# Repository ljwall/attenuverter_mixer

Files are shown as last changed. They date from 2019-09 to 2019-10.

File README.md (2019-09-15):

# Eurorack attenuverter and mixer module

Four channels, each with input -> attenuverter control -> output. Each input is
normaled to +5v if there is no jack in the input. Each output channel (after the
attenuverting stage) is also sent to a summing mixer, and to an analogue logic
or, a.k.a. the peaks part from [peaks and troughs](https://www.elby-designs.com/webtek/cgs/cgs26/cgs26_analogic.html).

If an individual output chnanel is patched, it's removed from the summing mixer
and the peaks output.

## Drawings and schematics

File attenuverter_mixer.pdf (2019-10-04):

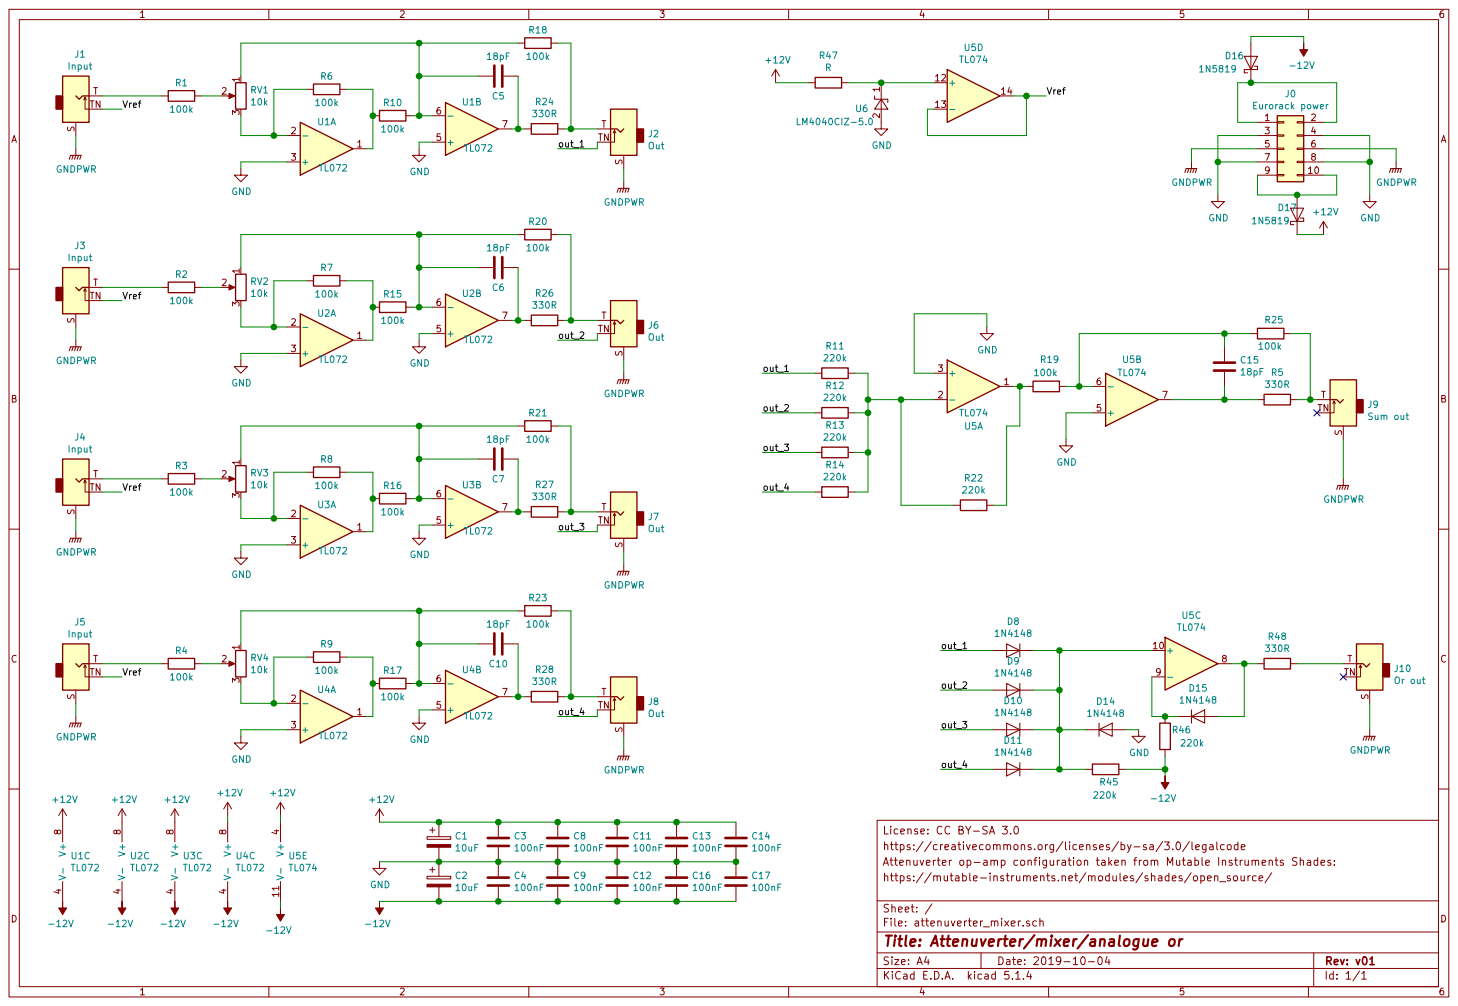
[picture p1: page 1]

9 | | 10

https://creativecommons.org/licenses/by-sa/3.0/legalcode
Attenuverter op-amp configuration taken from Mutable Instruments Shades:
File: attenuverter_mixer.sch Sheet: / https://mutable-instruments.net/modules/shades/open_source/

Id: 1/1 Title: Attenuverter/mixer/analogue or

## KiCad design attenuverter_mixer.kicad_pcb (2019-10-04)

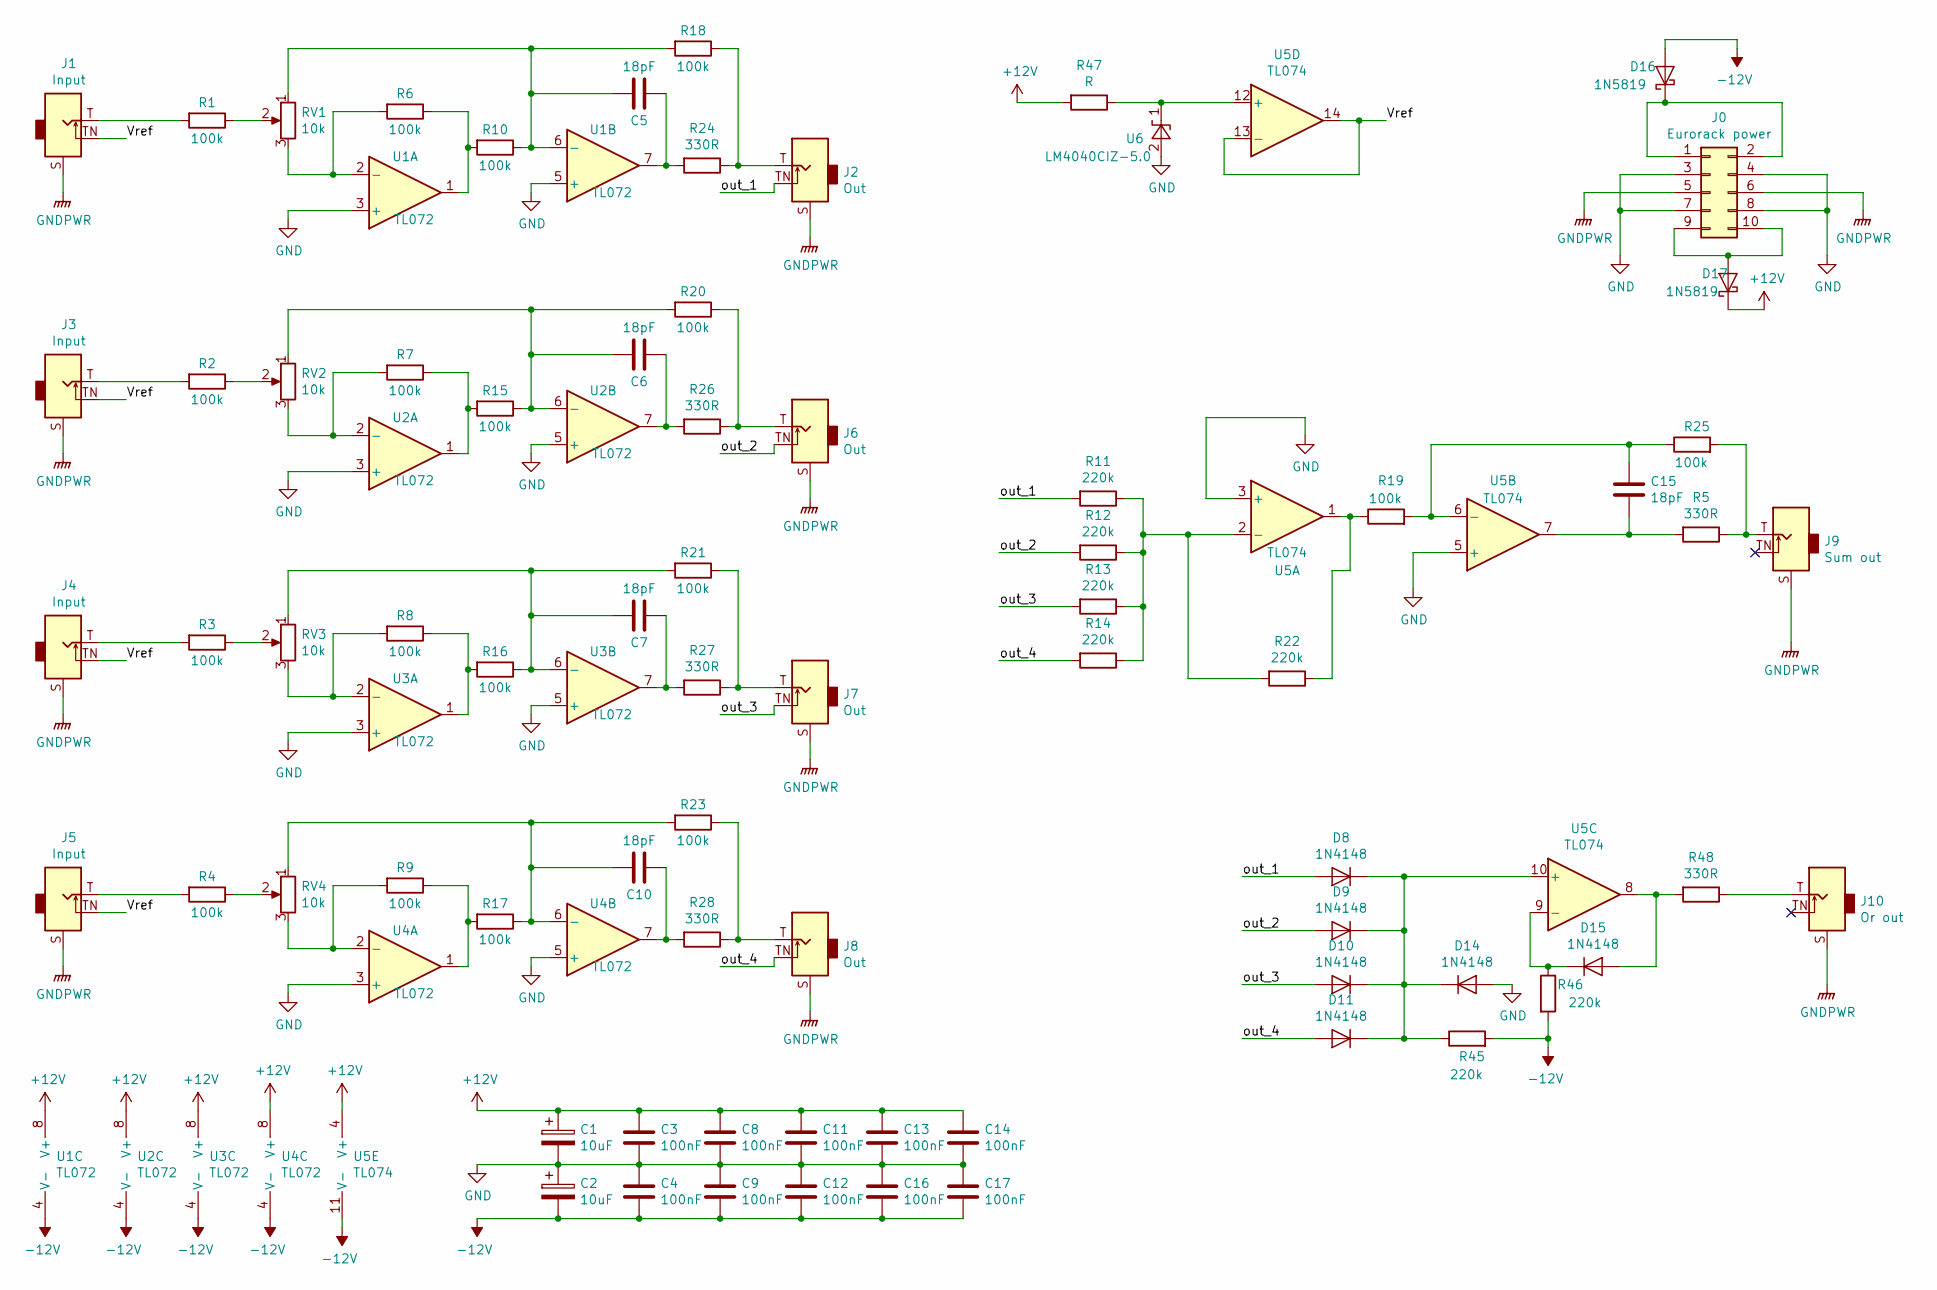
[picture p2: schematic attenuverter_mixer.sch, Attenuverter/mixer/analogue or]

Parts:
C1, C2: 10uF; CP_Radial_D5.0mm_P2.00mm
C3, C4, C8, C9, C11, C12, C13, C14, C16, C17: 100nF; C_Disc_D3.0mm_W1.6mm_P2.50mm
C5, C6, C7, C10, C15: 18pF; C_Disc_D3.0mm_W2.0mm_P2.50mm
D8, D9, D10, D11, D14, D15: 1N4148; D_DO-35_SOD27_P7.62mm_Horizontal
D16, D17: 1N5819; D_DO-41_SOD81_P10.16mm_Horizontal
J0: Eurorack power; PinSocket_2x05_P2.54mm_Vertical
J1, J3, J4, J5: Input; Jack_3.5mm_QingPu_WQP-PJ398SM_Vertical_CircularHoles
J2, J6, J7, J8: Out; Jack_3.5mm_QingPu_WQP-PJ398SM_Vertical_CircularHoles
J9: Sum out; Jack_3.5mm_QingPu_WQP-PJ398SM_Vertical_CircularHoles
J10: Or out; Jack_3.5mm_QingPu_WQP-PJ398SM_Vertical_CircularHoles
R1, R2, R3, R4, R6, R7, R8, R9, R10, R15, R16, R17, R18, R19, R20, R21, R23, R25: 100k; R_1206_3216Metric_Pad1.42x1.75mm_HandSolder
R5, R48: 330R; R_Axial_DIN0309_L9.0mm_D3.2mm_P2.54mm_Vertical
R11, R12, R13, R14, R22, R45, R46: 220k; R_1206_3216Metric_Pad1.42x1.75mm_HandSolder
R24, R26, R27, R28: 330R; R_Axial_DIN0309_L9.0mm_D3.2mm_P12.70mm_Horizontal
R47: R; R_Axial_DIN0309_L9.0mm_D3.2mm_P2.54mm_Vertical
RV1, RV2, RV3, RV4: 10k; Potentiometer_Alpha_RD901F-40-00D_Single_Vertical
U1, U2, U3, U4: TL072; SOIC-8_3.9x4.9mm_P1.27mm
U5: TL074; SOIC-14_3.9x8.7mm_P1.27mm
U6: LM4040CIZ-5.0; TO-92_Inline

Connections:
+12V: C1.1, C3.1, C8.1, C11.1, C13.1, C14.1, D17.1 (K), R47.2, U1.8 (V+), U2.8 (V+), U3.8 (V+), U4.8 (V+), U5.4 (V+)
-12V: C2.2, C4.2, C9.2, C12.2, C16.2, C17.2, D16.2 (A), R45.2, R46.2, U1.4 (V-), U2.4 (V-), U3.4 (V-), U4.4 (V-), U5.11 (V-)
/Vref: J1.TN, J3.TN, J4.TN, J5.TN, U5.13 (-), U5.14
/out_1: D8.2 (A), J2.TN, R11.2
/out_2: D9.2 (A), J6.TN, R12.2
/out_3: D10.2 (A), J7.TN, R13.2
/out_4: D11.2 (A), J8.TN, R14.2
GND: C1.2, C2.1, C3.2, C4.1, C8.2, C9.1, C11.2, C12.1, C13.2, C14.2, C16.1, C17.1, D14.2 (A), J0.3, J0.4, J0.7, J0.8, U1.3 (+), U1.5 (+), U2.3 (+), U2.5 (+), U3.3 (+), U3.5 (+), U4.3 (+), U4.5 (+), U5.3 (+), U5.5 (+), U6.2 (A)
GNDPWR: J0.5, J0.6, J1.S, J2.S, J3.S, J4.S, J5.S, J6.S, J7.S, J8.S, J9.S, J10.S
unnamed: C5.1, R24.2, U1.7
unnamed: C5.2, R10.1, R18.2, RV1.1, U1.6 (-)
unnamed: C6.1, R26.2, U2.7
unnamed: C6.2, R15.1, R20.2, RV2.1, U2.6 (-)
unnamed: C7.1, R27.2, U3.7
unnamed: C7.2, R16.1, R21.2, RV3.1, U3.6 (-)
unnamed: C10.1, R28.2, U4.7
unnamed: C10.2, R17.1, R23.2, RV4.1, U4.6 (-)
unnamed: C15.1, R5.2, U5.7
unnamed: C15.2, R19.2, R25.1, U5.6 (-)
unnamed: D8.1 (K), D9.1 (K), D10.1 (K), D11.1 (K), D14.1 (K), R45.1, U5.10 (+)
unnamed: D15.1 (K), R46.1, U5.9 (-)
unnamed: D15.2 (A), R48.2, U5.8
unnamed: D16.1 (K), J0.1, J0.2
unnamed: D17.2 (A), J0.9, J0.10
unnamed: J1.T, R1.2
unnamed: J2.T, R18.1, R24.1
unnamed: J3.T, R2.2
unnamed: J4.T, R3.2
unnamed: J5.T, R4.2
unnamed: J6.T, R20.1, R26.1
unnamed: J7.T, R21.1, R27.1
unnamed: J8.T, R23.1, R28.1
unnamed: J9.T, R5.1, R25.2
unnamed: J10.T, R48.1
unnamed: R1.1, RV1.2
unnamed: R2.1, RV2.2
unnamed: R3.1, RV3.2
unnamed: R4.1, RV4.2
unnamed: R6.2, RV1.3, U1.2 (-)
unnamed: R7.2, RV2.3, U2.2 (-)
unnamed: R8.2, RV3.3, U3.2 (-)
unnamed: R9.2, RV4.3, U4.2 (-)
unnamed: R6.1, R10.2, U1.1
unnamed: R11.1, R12.1, R13.1, R14.1, R22.2, U5.2 (-)
unnamed: R7.1, R15.2, U2.1
unnamed: R8.1, R16.2, U3.1
unnamed: R9.1, R17.2, U4.1
unnamed: R19.1, R22.1, U5.1
unnamed: R47.1, U5.12 (+), U6.1 (K)

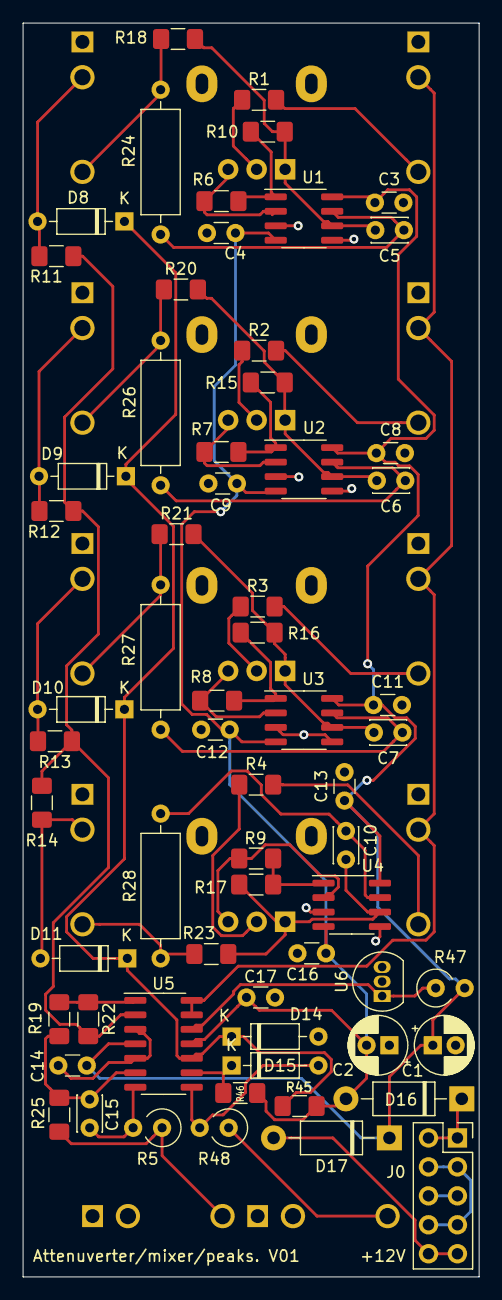
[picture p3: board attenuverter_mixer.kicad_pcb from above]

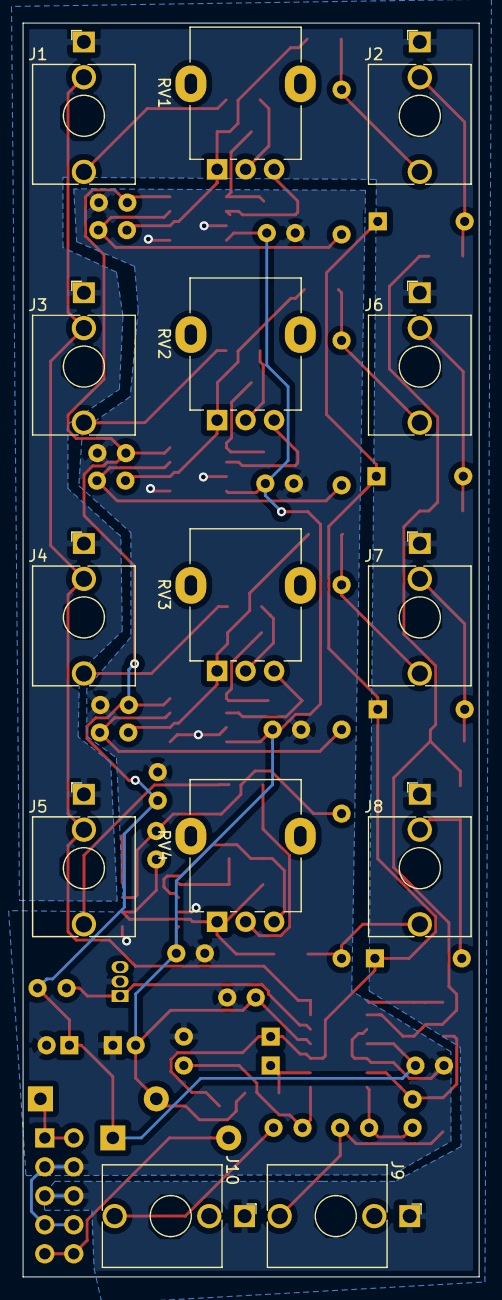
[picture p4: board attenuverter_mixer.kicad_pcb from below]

Board: 2 copper layers, 40.0 x 110.0 mm, 78 parts (14 on the bottom side), 49 nets.

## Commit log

2019-09-15 Add the missing 5v voltage reference
    [attenuverter_mixer.sch]
2019-09-15 Adjust peaks pull down resistors up to 1M
    [attenuverter_mixer.sch]
2019-09-24 assorted updates
    [attenuverter_mixer.sch]
2019-09-24 Remove TVS diodes from i/o
    [attenuverter_mixer.sch]
2019-09-24 remove two more TVS diodes; remove input resistors; use SM resistors
    [attenuverter_mixer.sch]
2019-09-27 Where it's at, just before changing the op amp configuration
    [attenuverter_mixer.kicad_pcb, attenuverter_mixer.sch]
2019-10-04 V01 as fabricated
    - Use surface mount 100K and 220K to allow single board.
    - Drop offset pots --- just have atteunuvert controls on each channel.
    [attenuverter_mixer-B_Cu.gbr, attenuverter_mixer-B_Mask.gbr, attenuverter_mixer-B_Paste.gbr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]

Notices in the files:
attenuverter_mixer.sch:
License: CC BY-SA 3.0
